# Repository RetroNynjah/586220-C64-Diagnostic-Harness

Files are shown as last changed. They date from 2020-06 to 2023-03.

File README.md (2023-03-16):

# Retro Ninja 586220 C64 Diagnostic Harness

Eagle schematics and boards plus a combined panel of the three different boards for a C64 586220 diagnostic harmess.

This version is based on the work of [Peter Schepers](https://ist.uwaterloo.ca/~schepers/diagnostic.html) and [Sven Petersen](https://github.com/svenpetersen1965/C64-Diagnostic-Rev.-586220-Harness).
The reason I made this version was to make the boards smaller so that all three boards can fit on one PCB panel and thereby reducing the cost of the PCB by two thirds when using the 10x10cm prototype offers from PCB houses like Seeed Studio.
Making a panel also has the advantage that you can order a paste stencil with the PCB panel which makes it very easy to solder the SMD components for all three boards at once which is good if you want to build a batch of boards.

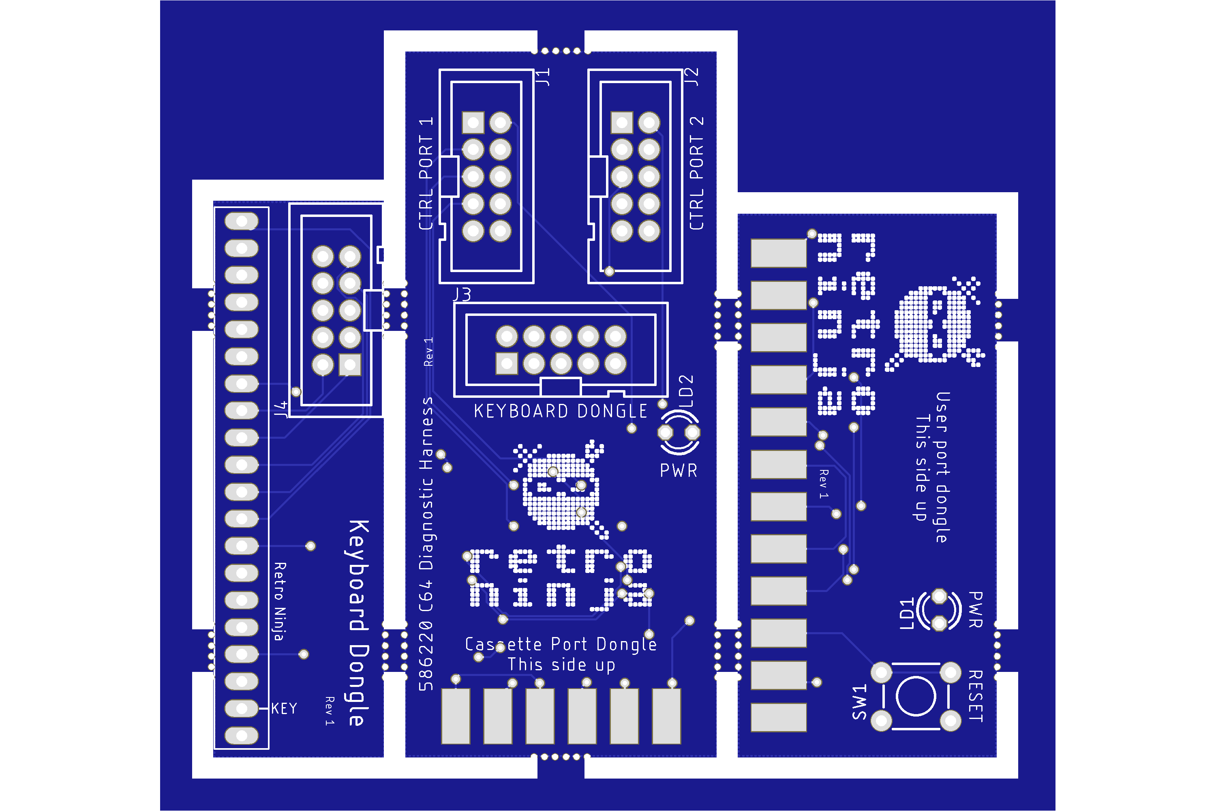
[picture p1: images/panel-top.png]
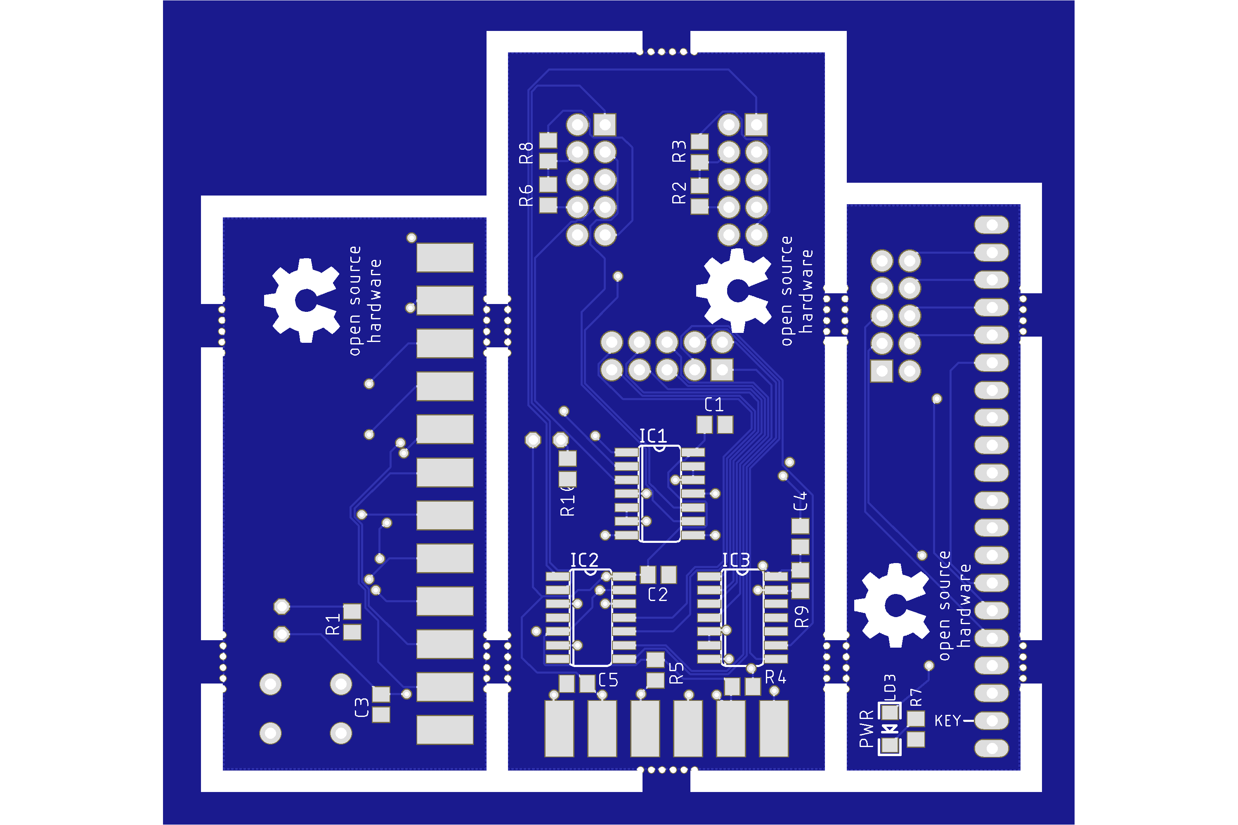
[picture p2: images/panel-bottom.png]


The program cartridge needed for the diagnostic program is a standard 8 Kilobyte cartridge running from $8000.
I will make schematics and gerbers for the cartridge available in a separate repository later.
ROM images for the cartridge can be found at [worldofjani.com](http://blog.worldofjani.com/?p=164).

A DIN connector loopback adapter is also required for testing the serial port. Connect pin 1 to pin 5 and connect pin 3 to pin 4.

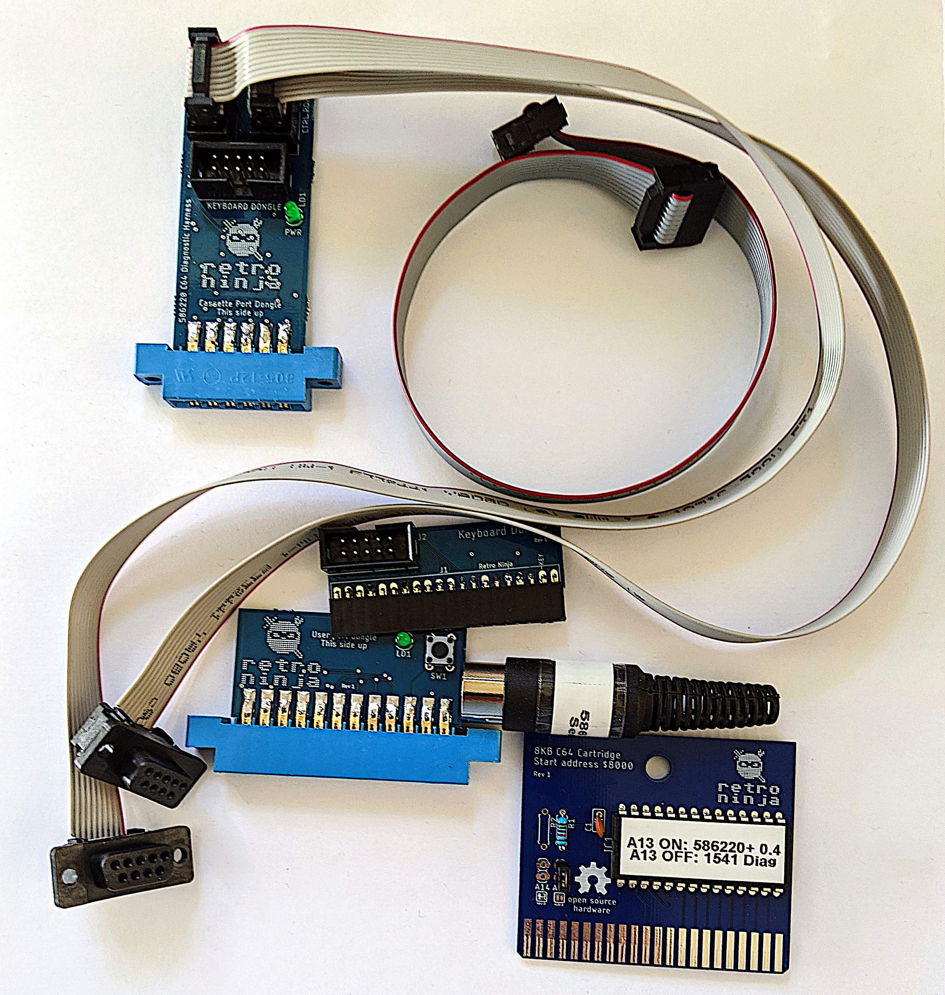
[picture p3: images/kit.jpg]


## BOM for Cassette Port
| Component | Pcs | Name | Comment |
 |:--------|---:|:---|:------|
 | C1,C2,C3,C4 | 4 | 100nF ceramic 0805 | |
 | CN1 | 1 | 12-pin (2x6) female edge connector | 3.96mm pitch |
 | IC1,IC2,IC3 | 3 | CD4066B SOIC-14 | Quad Bilateral Switch |
 | J1,J2,J3 | 3 | 10-pin IDC male | Shrouded connector recommended |
 | LD1 | 1 | LED 3mm | Power LED |
 | R1,R2,R5,R6 | 4 | 110K 0805 | 120k works too |
 | R3,R9 | 2 | 330R 0805 | R9=current limiter for LED, 560R or even higher should be ok for R9 |
 | R8 | 1 | 10k 0805 | |
 | R4 | 1 | 150R 0805 | |
 
## BOM for User Port
 | Component | Pcs | Name | Comment |
 |:--------|---:|:---|:------|
 | C3 | 1 | 100nF ceramic 0805| |
 | LD1 | 1 | LED 3mm | Power LED |
 | R1 | 1 | 330R 0805 | Current limiter for LED. 560R or even higher should be ok |
 | SW1 | 1 | Tactile Switch 6x6mm | |
 | X1 | 1 | 24-pin (2x12) female edge connector | 3.96mm pitch |
 
## BOM for Keyboard
 | Component | Pcs | Name | Comment |
 |:--------|---:|:---|:------|
 | J1 | 1 | 20pin female header right angle|2,54mm pitch |
 | J2 | 1 | 10-pin IDC male|shrouded connector recommended |
 | LD1 | 1 | LED 1206 | Power LED |
 | R1 | 1 | 330R | Current limiter for LED. 560R or even higher should be ok |
 
## Cables
### Control port cable (2 pcs) ###
9-pin female D-SUB with IDC connection in one end and a 10-pin female IDC plug in the other end.
For each control port you need a 9 or 10 pin ribbon cable that is at least 45cm after connectors have been installed.

### Keyboard cable ###
10-pin ribbon cable with 10-pin female IDC plug on each end.

## Serial port ##
6-pin male DIN connector

Retro Ninja

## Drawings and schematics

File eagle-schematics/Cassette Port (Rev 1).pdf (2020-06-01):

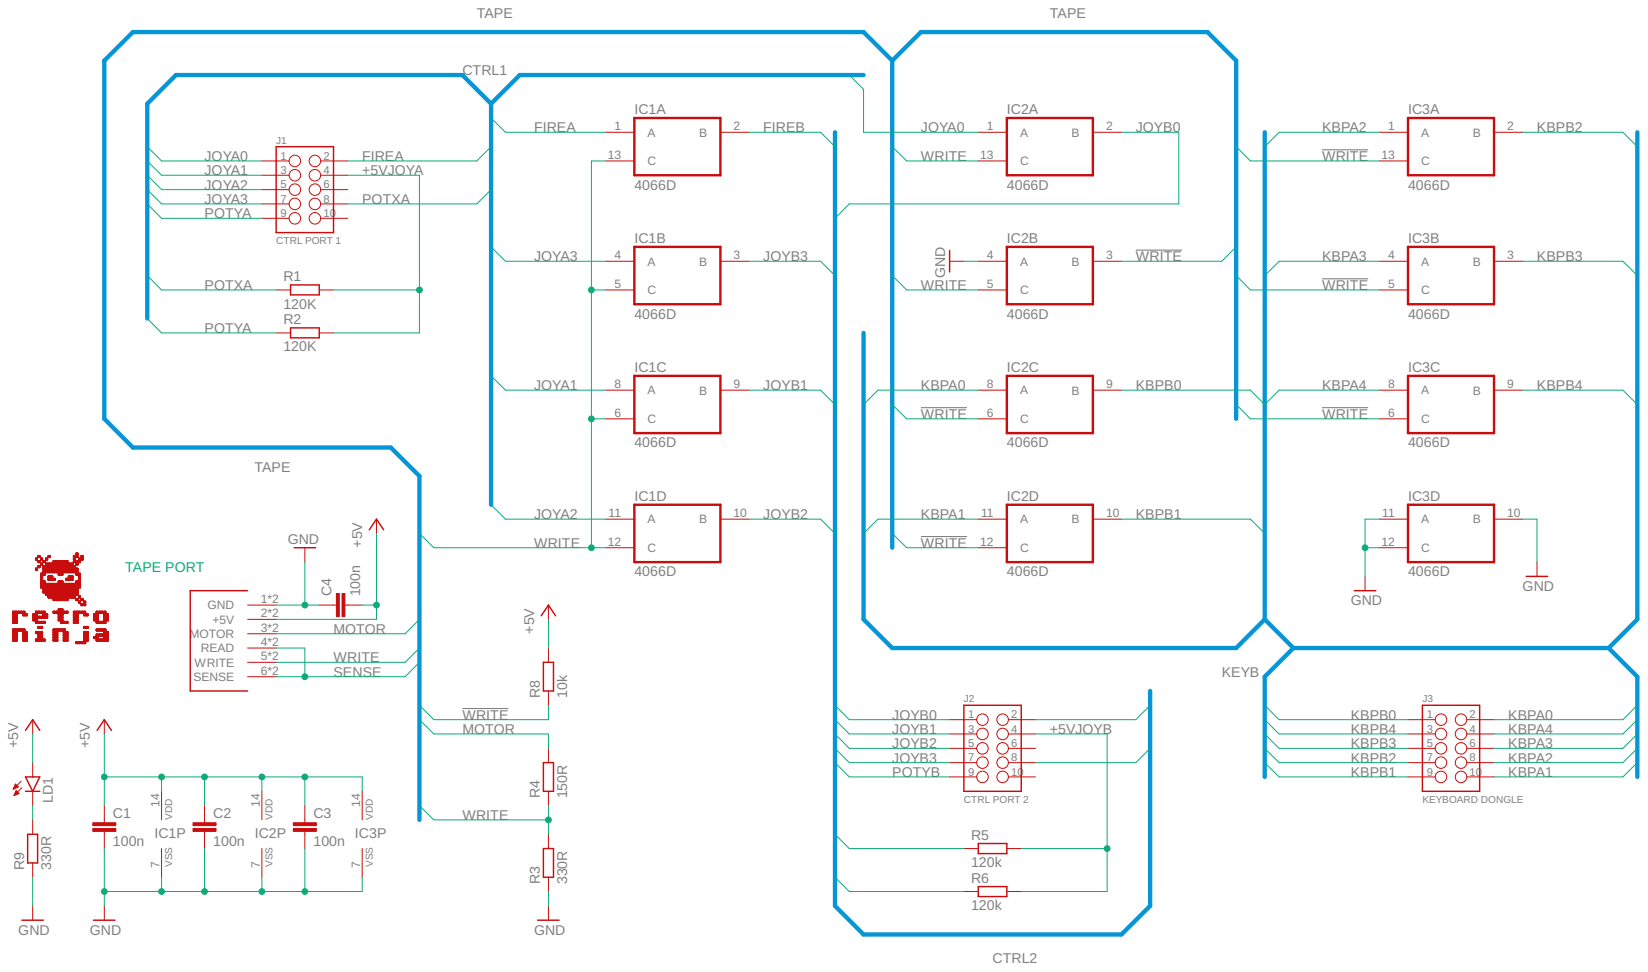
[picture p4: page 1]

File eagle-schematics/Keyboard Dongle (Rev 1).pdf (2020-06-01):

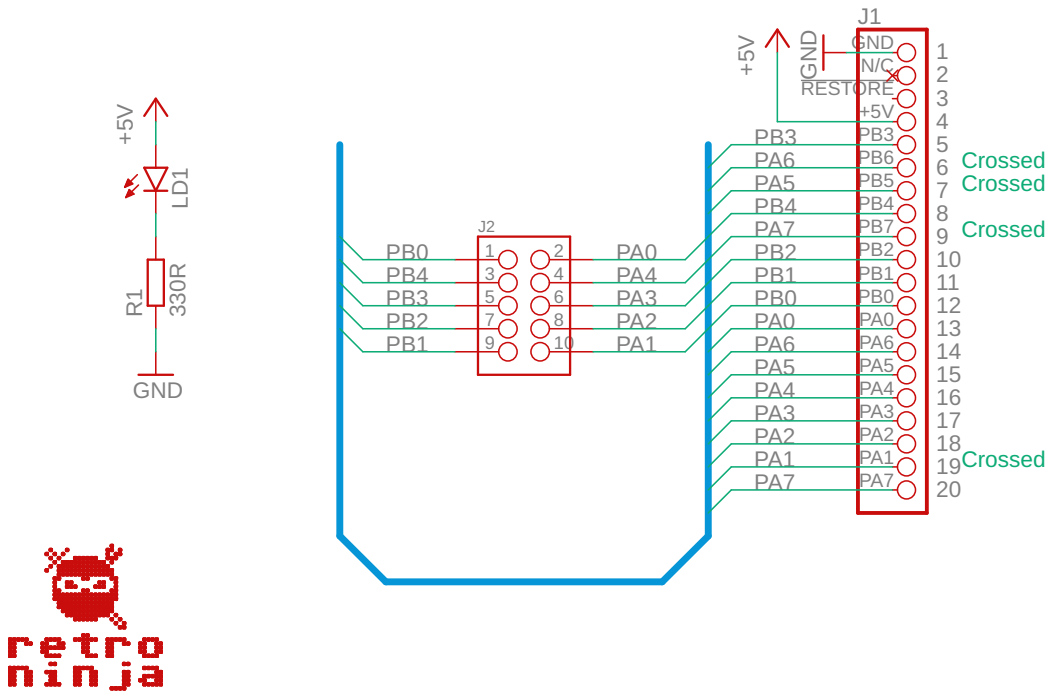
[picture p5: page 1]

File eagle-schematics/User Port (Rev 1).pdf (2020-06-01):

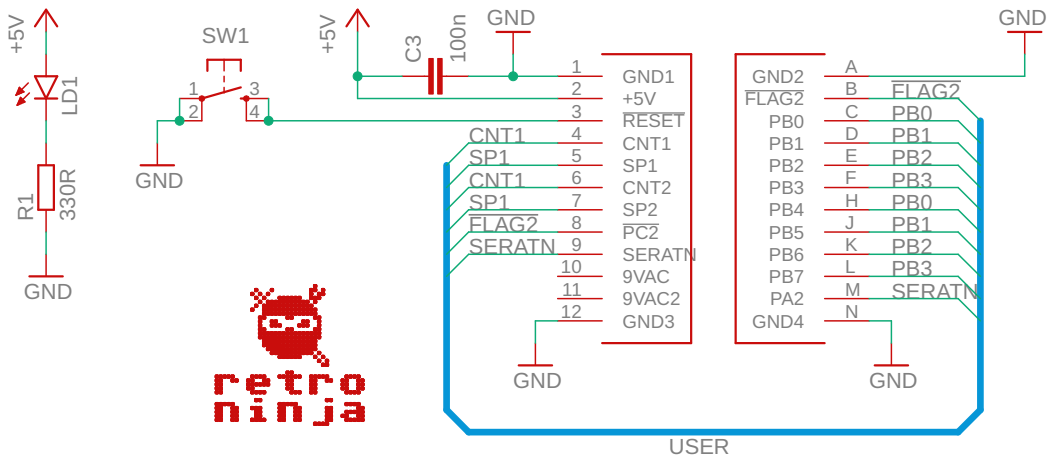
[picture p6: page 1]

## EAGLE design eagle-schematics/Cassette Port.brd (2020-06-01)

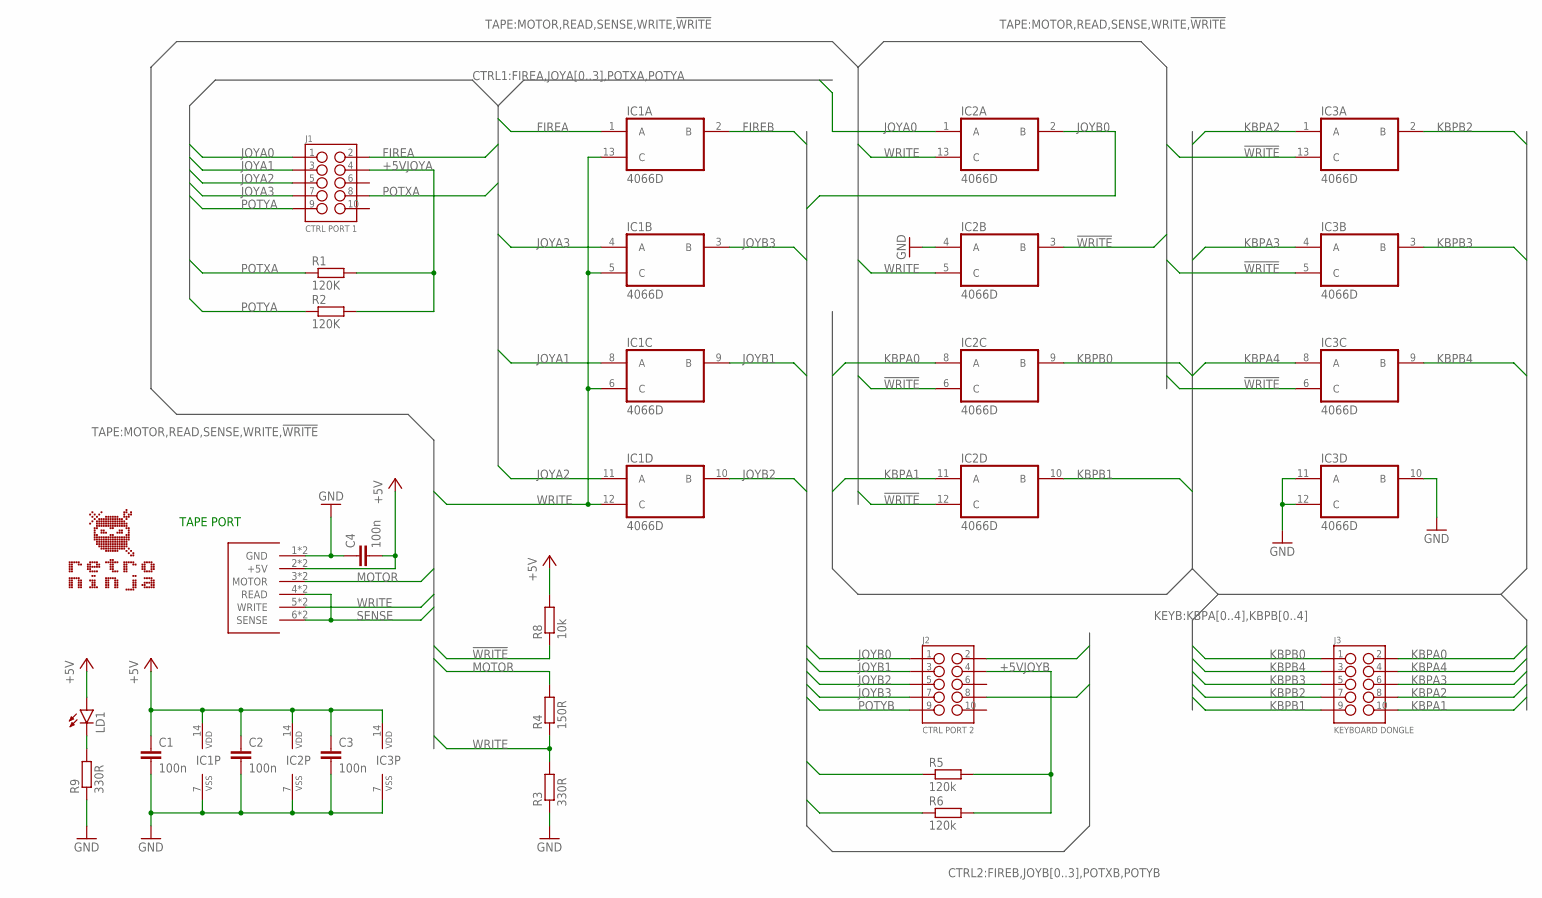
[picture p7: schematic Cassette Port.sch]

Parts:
C1, C2, C3, C4: 100n; C0805
CN1: C64_CASSETTE_PORT_CONNECTOR_SIDE; C64_CASSETTE_CONNECTOR
IC1, IC2, IC3: 4066D; SO14
J1: CTRL PORT 1; 2X5_HEADER_WALLED
J2: CTRL PORT 2; 2X5_HEADER_WALLED
J3: KEYBOARD DONGLE; 2X5_HEADER_WALLED
LD1: LED3MM
R1, R2: 120K; R0805
R3, R9: 330R; R0805
R4: 150R; R0805
R5, R6: 120k; R0805
R8: 10k; R0805
U$1: RETRONINJA_TEXT; RETRONINJA_TEXT_17MM

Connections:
!WRITE: IC2.3 (B), IC2.6 (C), IC2.12 (C), IC3.5 (C), IC3.6 (C), IC3.13 (C), R8.1
+5V: C1.1, C2.1, C3.1, C4.2, CN1.2 (+5V), CN1.B (+5V), IC1.14 (VDD), IC2.14 (VDD), IC3.14 (VDD), LD1.A, R8.2
+5VJOYA: J1.4, R1.2, R2.2
+5VJOYB: J2.4, R5.2, R6.2
FIREA: IC1.1 (A), J1.2
FIREB: IC1.2 (B), J2.2
GND: C1.2, C2.2, C3.2, C4.1, CN1.1 (GND), CN1.A (GND), IC1.7 (VSS), IC2.4 (A), IC2.7 (VSS), IC3.7 (VSS), IC3.10 (B), IC3.11 (A), IC3.12 (C), R3.1, R9.1
JOYA0: IC2.1 (A), J1.1
JOYA1: IC1.8 (A), J1.3
JOYA2: IC1.11 (A), J1.5
JOYA3: IC1.4 (A), J1.7
JOYB0: IC2.2 (B), J2.1
JOYB1: IC1.9 (B), J2.3
JOYB2: IC1.10 (B), J2.5
JOYB3: IC1.3 (B), J2.7
KBPA0: IC2.8 (A), J3.2
KBPA1: IC2.11 (A), J3.10
KBPA2: IC3.1 (A), J3.8
KBPA3: IC3.4 (A), J3.6
KBPA4: IC3.8 (A), J3.4
KBPB0: IC2.9 (B), J3.1
KBPB1: IC2.10 (B), J3.9
KBPB2: IC3.2 (B), J3.7
KBPB3: IC3.3 (B), J3.5
KBPB4: IC3.9 (B), J3.3
MOTOR: CN1.3 (MOTOR), CN1.C (MOTOR), R4.2
unnamed: LD1.K (C), R9.2
POTXA: J1.8, R1.1
POTXB: J2.8, R5.1
POTYA: J1.9, R2.1
POTYB: J2.9, R6.1
SENSE: CN1.4 (READ), CN1.6 (SENSE), CN1.D (READ), CN1.F (SENSE)
WRITE: CN1.5 (WRITE), CN1.E (WRITE), IC1.5 (C), IC1.6 (C), IC1.12 (C), IC1.13 (C), IC2.5 (C), IC2.13 (C), R3.2, R4.1

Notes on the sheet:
TAPE PORT

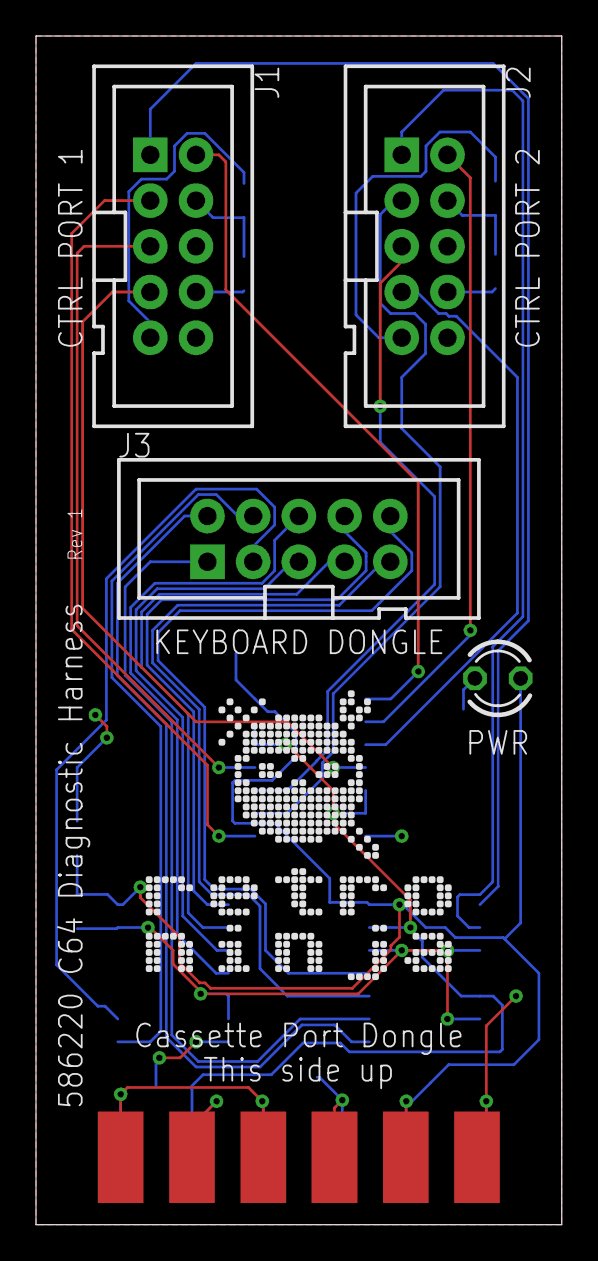
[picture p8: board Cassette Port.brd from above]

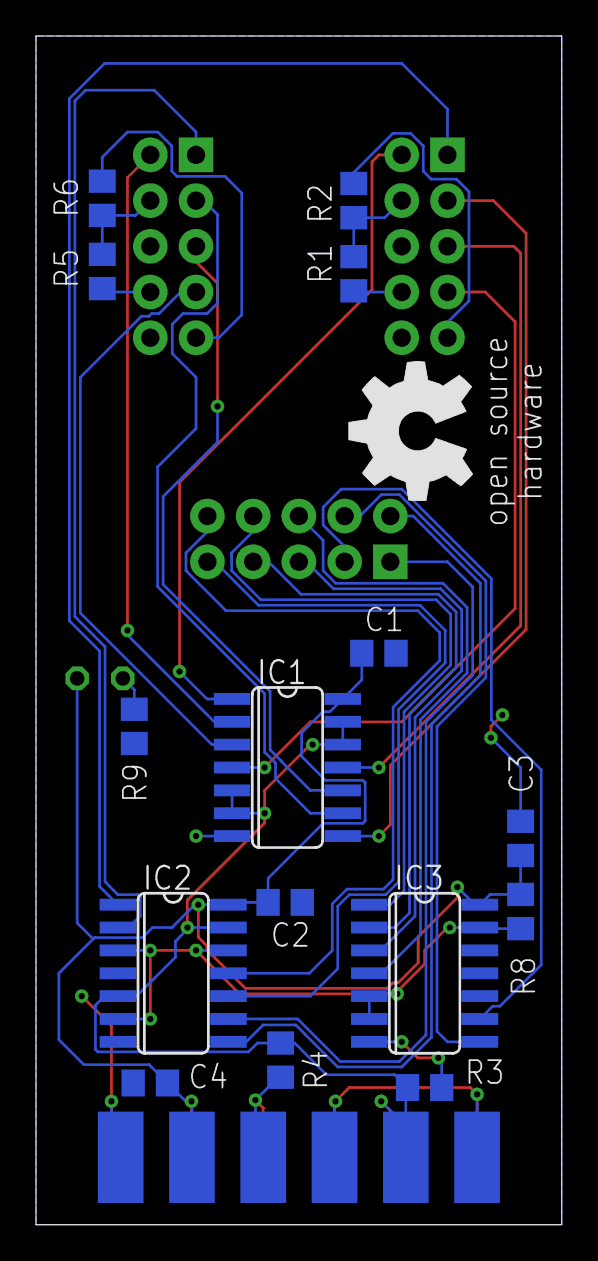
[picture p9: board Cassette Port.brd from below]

Board: 2 copper layers, 29.2 x 66.0 mm, 22 parts (16 on the bottom side), 33 nets.

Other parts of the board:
U$2: OSHW_8MM

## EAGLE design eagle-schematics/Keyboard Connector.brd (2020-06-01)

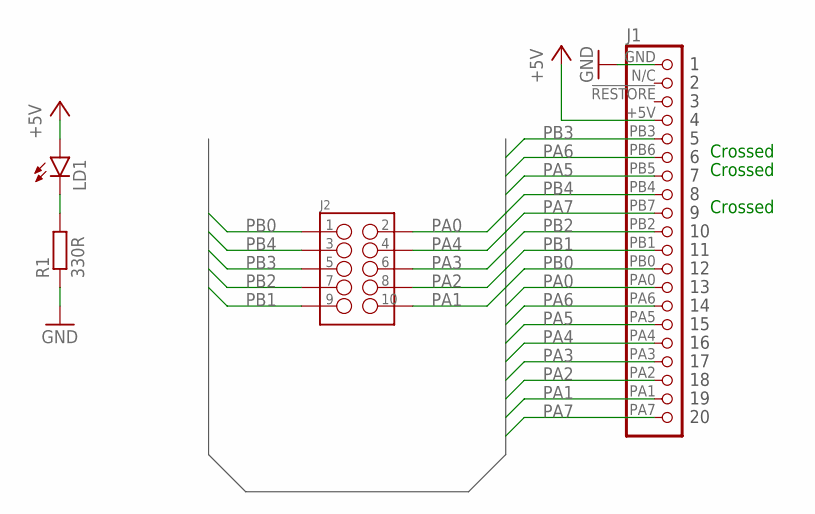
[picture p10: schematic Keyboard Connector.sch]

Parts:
J1: C64_KEYBOARD_CONNECTOR
J2: HEADER_2X5-WALLED; 2X5_HEADER_WALLED
LD1: LED1206; LED-1206
R1: 330R; R0805

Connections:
+5V: J1.+5V, LD1.A
GND: J1.GND, R1.1
unnamed: LD1.C, R1.2
PA0: J1.PA0, J2.2
PA1: J1.PA1, J2.10
PA2: J1.PA2, J2.8
PA3: J1.PA3, J2.6
PA4: J1.PA4, J2.4
PA5: J1.PA5, J1.PB5
PA6: J1.PA6, J1.PB6
PA7: J1.PA7, J1.PB7
PB0: J1.PB0, J2.1
PB1: J1.PB1, J2.9
PB2: J1.PB2, J2.7
PB3: J1.PB3, J2.5
PB4: J1.PB4, J2.3

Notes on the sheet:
Crossed

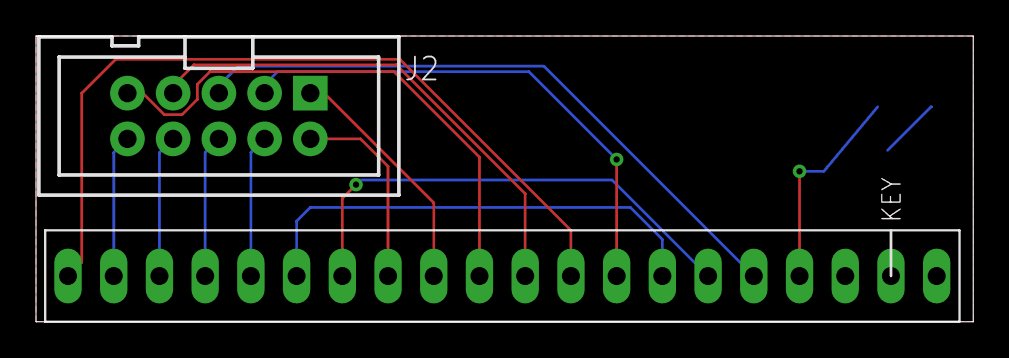
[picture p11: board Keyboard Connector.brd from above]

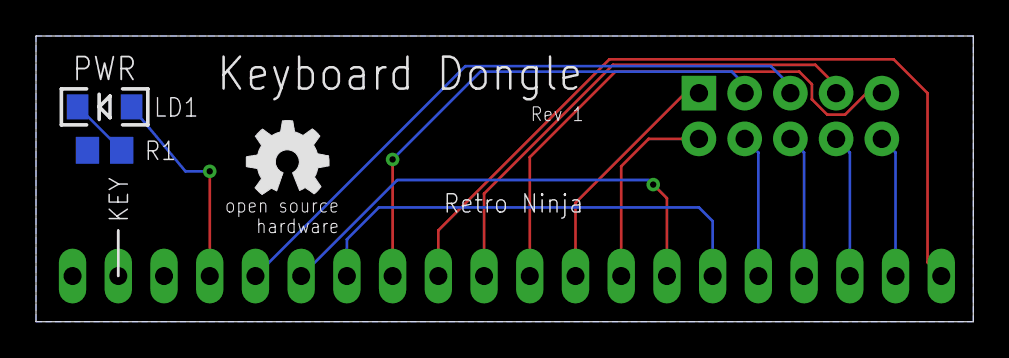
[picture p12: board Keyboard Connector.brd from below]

Board: 2 copper layers, 52.1 x 15.9 mm, 5 parts (3 on the bottom side), 16 nets.

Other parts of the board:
U$1: OSHW_5MM

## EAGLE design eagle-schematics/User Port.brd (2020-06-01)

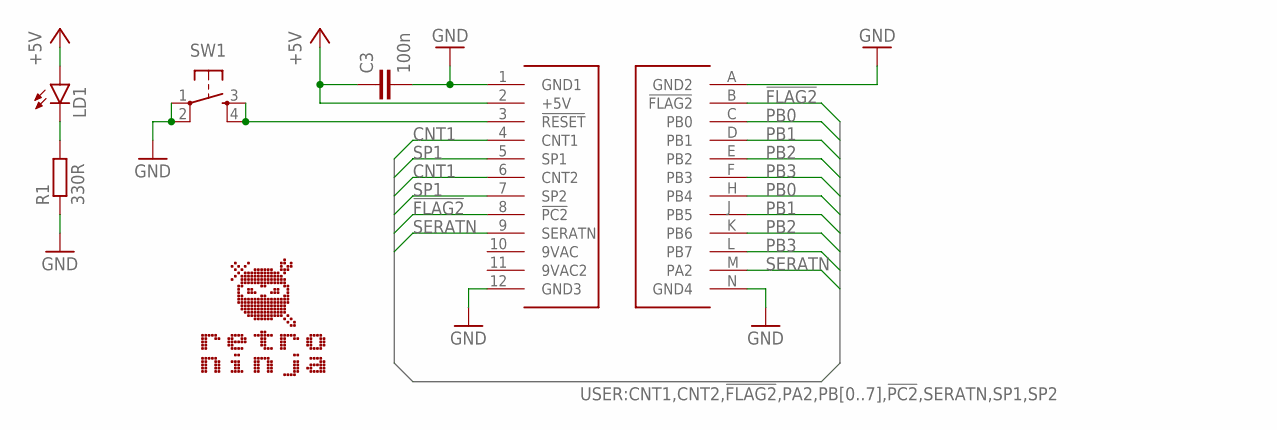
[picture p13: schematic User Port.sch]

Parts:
C3: 100n; C0805
LD1: LED3MM
R1: 330R; R0805
SW1: TAC_SWITCHPTH; TACTILE-PTH
U$1: RETRONINJA_TEXT; RETRONINJA_TEXT_17MM
X1: C64_USER_PORT_CONNECTOR_SIDE; C64_USER_PORT_DEVICE_CONNECTOR

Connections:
9VAC: X1.10 (9VAC)
9VAC2: X1.11 (9VAC2)
!FLAG2: X1.8 (!PC2), X1.B (!FLAG2)
!RESET: SW1.3, SW1.4, X1.3 (!RESET)
+5V: C3.1, LD1.A, X1.2 (+5V)
CNT1: X1.4 (CNT1), X1.6 (CNT2)
GND: C3.2, R1.1, SW1.1, SW1.2, X1.1 (GND1), X1.12 (GND3), X1.A (GND2), X1.N (GND4)
unnamed: LD1.K (C), R1.2
PB0: X1.C (PB0), X1.H (PB4)
PB1: X1.D (PB1), X1.J (PB5)
PB2: X1.E (PB2), X1.K (PB6)
PB3: X1.F (PB3), X1.L (PB7)
SERATN: X1.9 (SERATN), X1.M (PA2)
SP1: X1.5 (SP1), X1.7 (SP2)

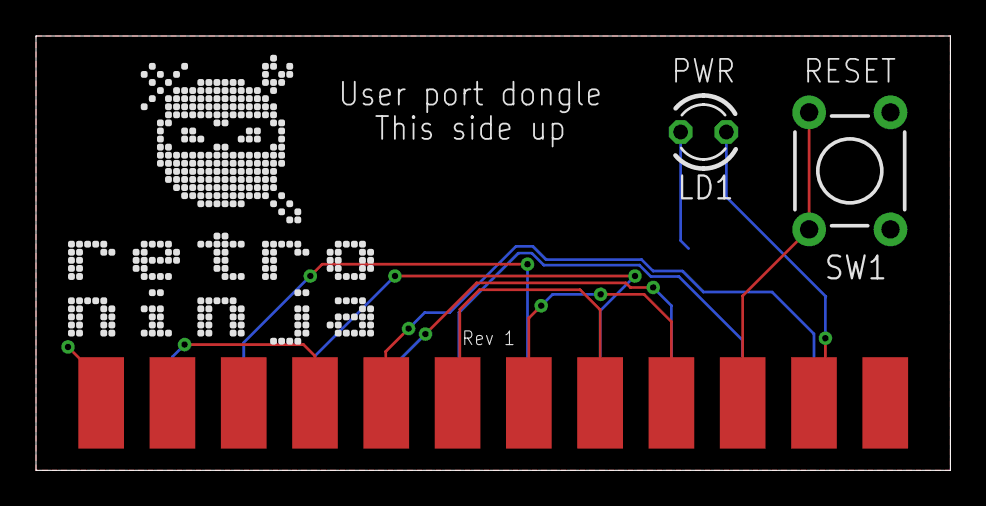
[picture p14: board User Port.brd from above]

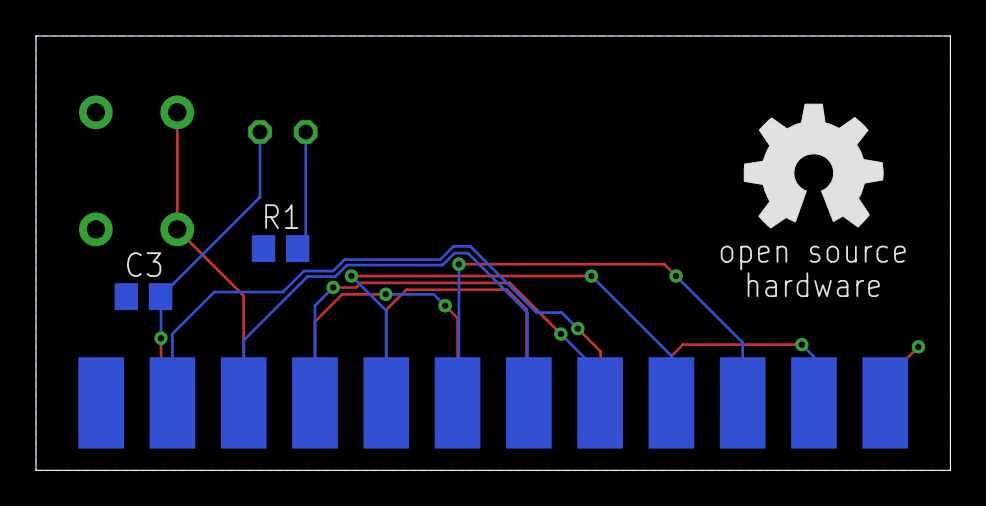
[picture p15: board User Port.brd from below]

Board: 2 copper layers, 50.8 x 24.1 mm, 7 parts (3 on the bottom side), 12 nets.

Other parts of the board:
U$2: OSHW_8MM

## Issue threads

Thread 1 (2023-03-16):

R8 Missing from the bom list in readme

Shadowtrance, 2023-03-16:
Thanks for making this as an easy one pcb order solution.
R8 is missing from the bom list which according to the schematics is a 10k resistor.

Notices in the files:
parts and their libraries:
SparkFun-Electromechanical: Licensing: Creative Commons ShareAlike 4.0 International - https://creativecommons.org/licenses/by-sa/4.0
